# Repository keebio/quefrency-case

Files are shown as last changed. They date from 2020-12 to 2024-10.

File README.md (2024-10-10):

# Quefrency Keyboard Case

Case files for the [Quefrency](https://keeb.io/collections/quefrency-split-staggered-65-keyboard).

## Enclosed Case

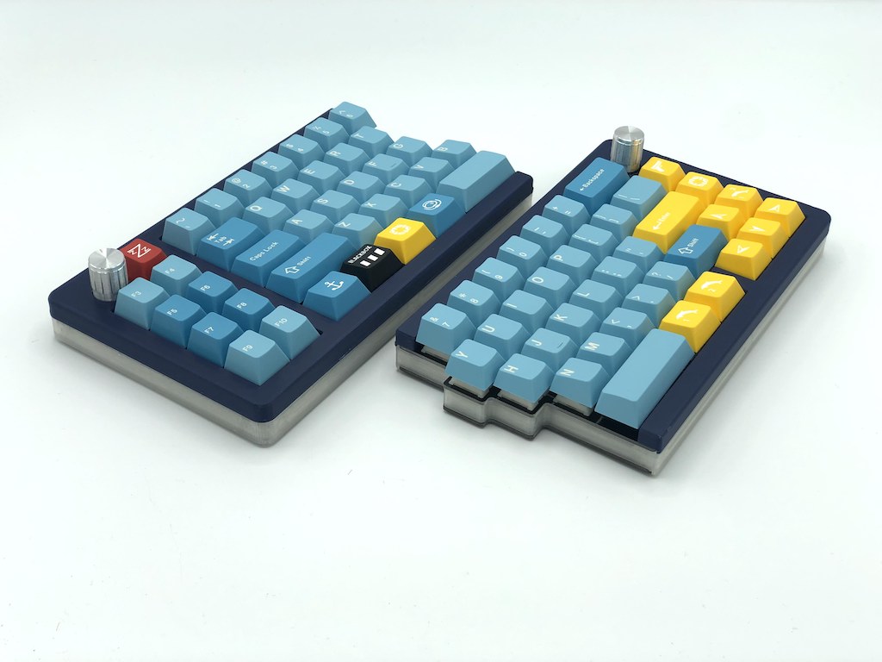
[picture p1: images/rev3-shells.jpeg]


Inside of the [enclosed-case directory](enclosed-case/) are files to print an enclosing shell around the board. They will need to be used in conjuction with the [FR4](https://keeb.io/products/quefrency-fr4-plates?utm_source=github) or [Aluminum plates](https://keeb.io/products/quefrency-black-aluminum-plates?utm_source=github) from the store.

These files are compatible with Rev. 2 through 6. For Rev. 2, use the middle layer files marked with `Rev. 2`.

## Rev. 3-6

The only difference between Rev. 2 and 3 is that Rev. 3 replaced the TRRS port with a USB-C port.

## License

These case files are released under the MIT License.

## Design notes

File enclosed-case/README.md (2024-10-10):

## Rev. 3-6 Case files



The top shell and mid layer files in this folder are to be used with FR4 plates. Each edge has been extended out by 2mm to cover up the sides of the FR4 plates.

The top shell has been designed to be threaded into directly from underneath using M2 screws that are 16mm in length.

For the right 65% half with blocker, the blocker is for the 2.75u/1.25u/1.25u/blocker/1u/1u/1u bottom row configuration.

These files are compatible with Rev. 3-6. If you have the prototype version of the Rev. 4 (Red PCB), the right half PCB is a bit wider, so you will need to use the `Rev. 4 Proto` version of the right half files. The regular version of the Rev. 4 has a purple PCB.

### Rev. 6

The left half PCB for the Rev. 6 slightly sticks out more on the right edge of the PCB, so it is not compatible with the mid layer STLs for Rev. 3-5. Use the Rev. 6 ones for Left Macro or Left No Macro, as the wall has been made thinner at that portion to allow the PCB to fit into the case properly.

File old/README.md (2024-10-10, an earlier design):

## Rev. 1 vs. Rev. 2

The difference between Rev 1 and Rev 2 plates are the following:

- Rev 2 does not have Alps support, while Rev 1 does
- Rev 2 adds ISO support and a few more bottom row layout options
- Rev 2 has a different arrangement of screw/standoff holes to allow for an acrylic mid layer to be used

## Rev. 2

All of the DXF files are in metric (millimeters).

### Switch Plates
The plate files in the [main rev2 directory](rev2/) are designed for 1.5mm thick plates. If doing acrylic plates, then either a thickness of 3mm or 5mm should be used. Files for these thicker plates can be found in the [3mm Plates](rev2/3mm Plates) and [5mm Plates](rev2/5mm Plates) directories. The difference with these thicker plates is that the stabilizer cutouts are larger to accomdate the stabilzer housing and wire.

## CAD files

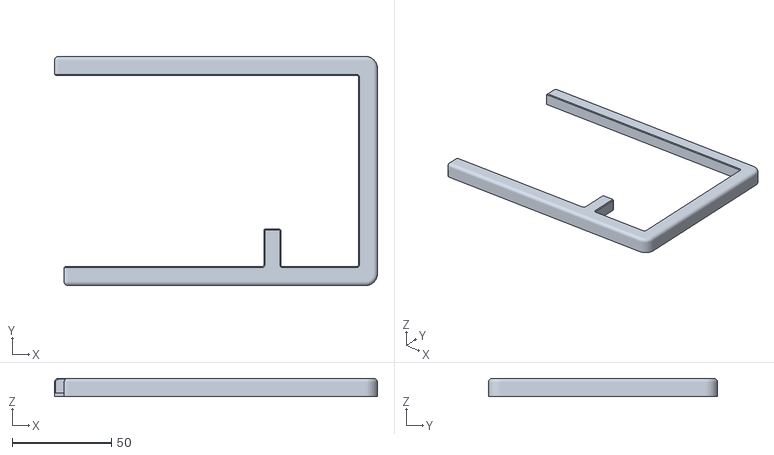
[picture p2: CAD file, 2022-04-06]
enclosed-case/Filleted Top Shells/Top Shell - Right 60 with Blocker.stl
162.4 x 115.2 x 9.30

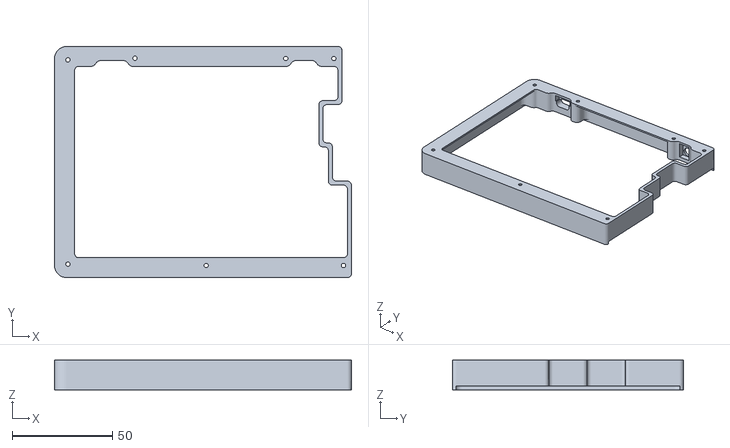
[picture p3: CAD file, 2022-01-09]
enclosed-case/Rev. 2/Mid Layer - Left No Macro for Rev. 2.stl
148.1 x 115.3 x 14.8

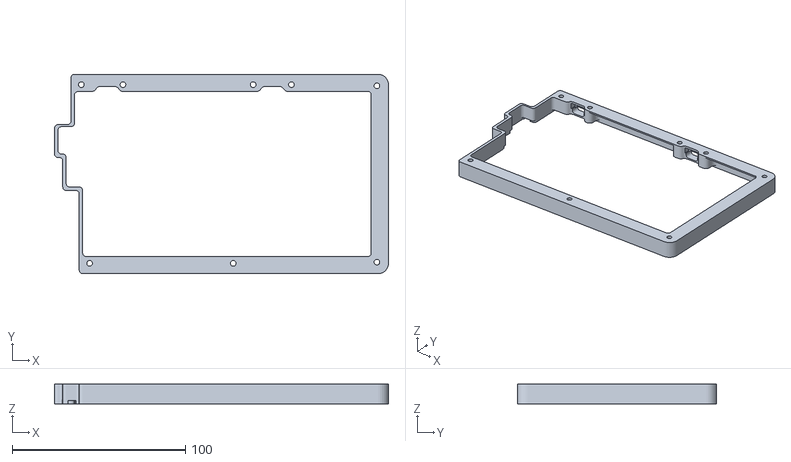
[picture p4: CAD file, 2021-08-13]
enclosed-case/Rev. 4 Proto/Mid Layer - Right 65 for Rev. 4 Proto.stl
193.0 x 115.2 x 11.3

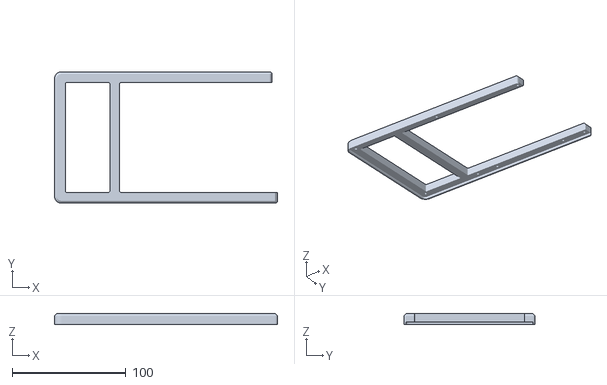
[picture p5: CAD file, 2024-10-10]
enclosed-case/Top Shell - Left Macro.stl
195.7 x 115.3 x 9.30

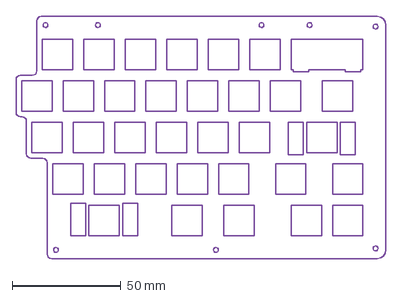
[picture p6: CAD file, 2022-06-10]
plates/switch-plate-blockered-right-60.dxf
169.9 x 111.2 mm

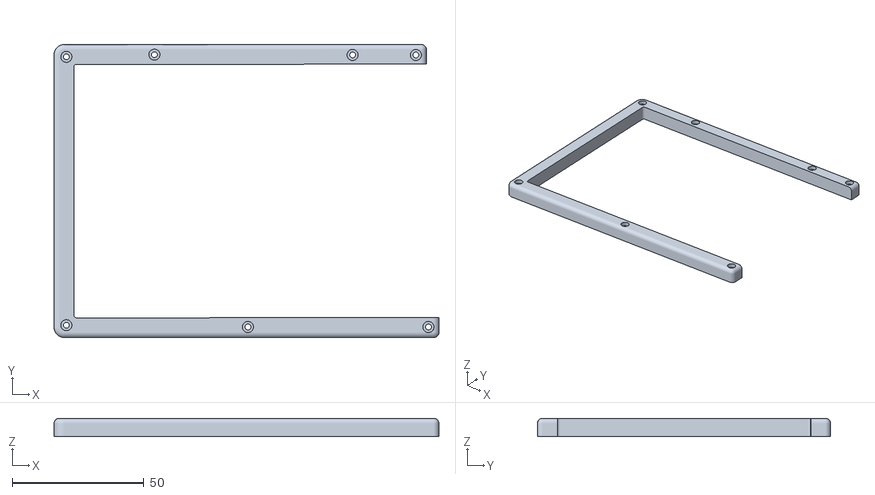
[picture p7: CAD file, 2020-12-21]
rev2/Top Shell - Left.stl
146.1 x 111.3 x 7.00

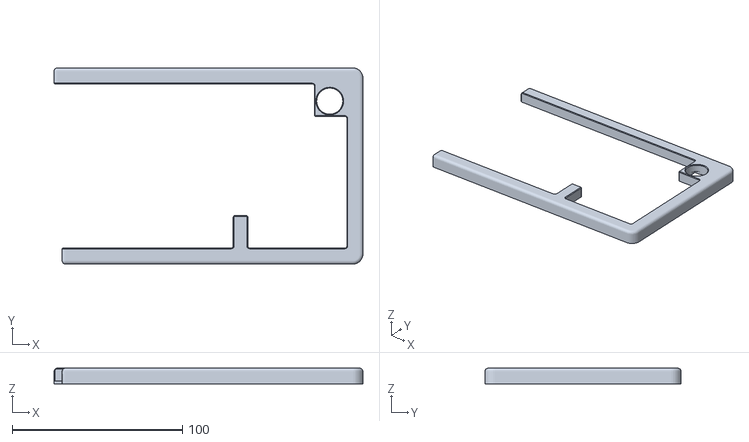
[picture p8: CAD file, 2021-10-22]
enclosed-case/Filleted Top Shells/Top Shell - Right 65 with Encoder and Blocker.stl
181.4 x 115.2 x 9.30

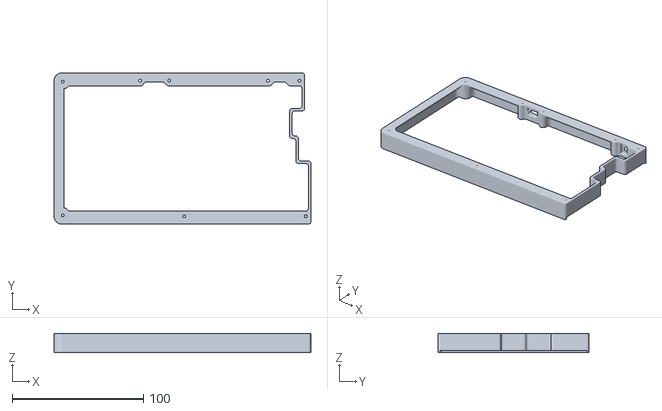
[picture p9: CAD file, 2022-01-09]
enclosed-case/Rev. 2/Mid Layer - Left Macro for Rev. 2.stl
195.7 x 115.3 x 14.8

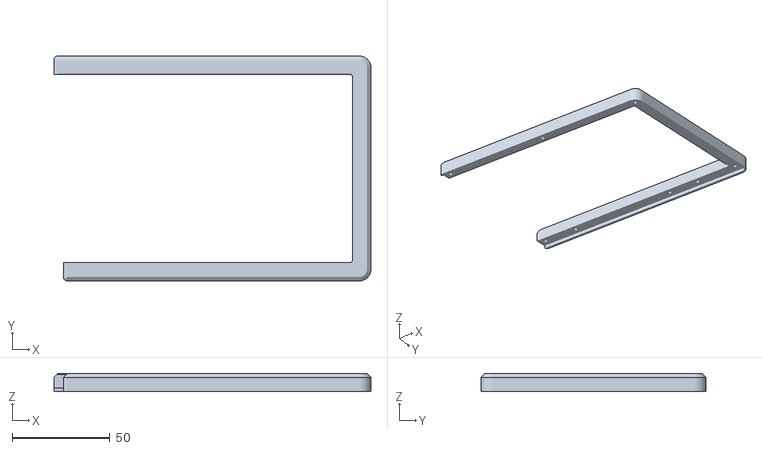
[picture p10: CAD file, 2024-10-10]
enclosed-case/Top Shell - Right 60.stl
162.4 x 115.2 x 9.30

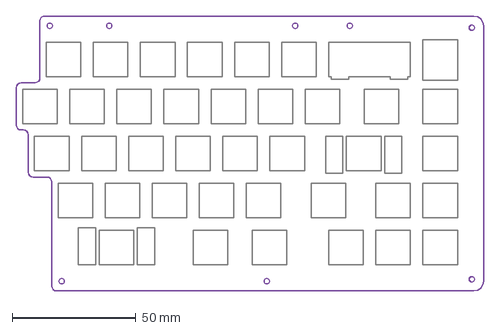
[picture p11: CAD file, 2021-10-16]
plates/switch-plate-blockered-right-65.dxf
189.0 x 111.2 mm

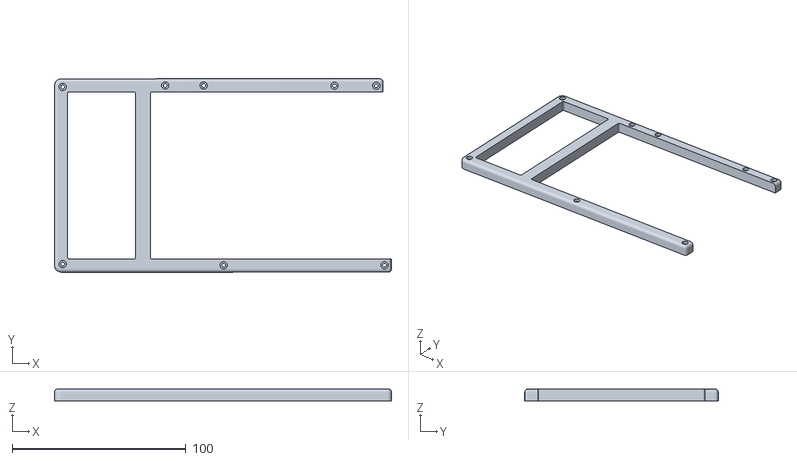
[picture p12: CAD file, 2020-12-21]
rev2/Top Shell - Left Macro.stl
193.7 x 111.3 x 7.00

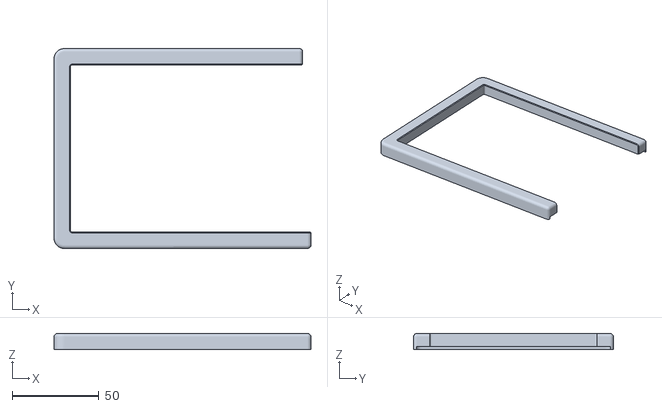
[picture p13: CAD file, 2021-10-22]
enclosed-case/Filleted Top Shells/Top Shell - Left 60.stl
148.1 x 115.3 x 9.30

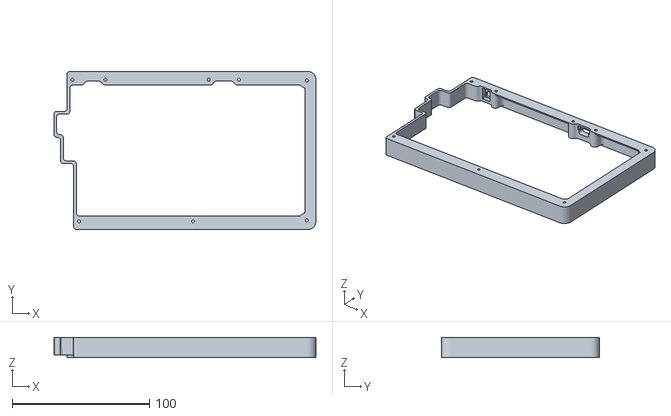
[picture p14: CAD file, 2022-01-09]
enclosed-case/Rev. 2/Mid Layer - Right 65 for Rev. 2.stl
191.0 x 115.2 x 14.8

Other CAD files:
rev2/3mm Plates/switch-plate-3mm-right-65.dxf
rev2/5mm Plates/switch-plate-5mm-right.dxf
rev2/3mm Plates/switch-plate-3mm-left.dxf
rev2/5mm Plates/switch-plate-5mm-left.dxf
enclosed-case/Top Shell - Left Macro and Encoder.stl
enclosed-case/Bottom Wedge - Left Macro.stl
enclosed-case/Bottom Wedge - Left No Macro.stl
enclosed-case/Bottom Wedge - Right 60.stl
enclosed-case/Bottom Wedge - Right 65.stl
enclosed-case/Filleted Top Shells/Quefrency Top Shells All - Fillet.f3d
enclosed-case/Filleted Top Shells/Top Shell - Left Macro with Encoder.stl
enclosed-case/Filleted Top Shells/Top Shell - Left Macro.stl
enclosed-case/Filleted Top Shells/Top Shell - Right 60.stl
enclosed-case/Filleted Top Shells/Top Shell - Right 65 for Rev. 4 Proto.stl
enclosed-case/Filleted Top Shells/Top Shell - Right 65 with Blocker.stl
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

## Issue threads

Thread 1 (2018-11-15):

Create 3D print top and bottom pieces

nooges, 2018-11-15:

szaghi, 2019-05-21:
My friend Luca has create the top and bottom plates design (for the 65% version), you can find them here

https://www.thingiverse.com/thing:3644626

danseely, 2019-05-28:
@nooges does this refer to entire case top & bottom parts? I'd love files for a hi-profile top lip, not sure if that would be included in what you were thinking here, or if you'd rather I make another issue just for that 😀

Closed 2021-11-01.

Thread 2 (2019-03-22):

too much tight tolerance for 3D print

szaghi, 2019-03-22:
Hi @nooges

thank you very much for sharing your work.

I have 3D printed your middle layers and they are great! However, the *tolerance" of the holes for usb and jack cables are too much "tight": they fit perfectly, but they must be installed before the pro micro are soldered and cannot be removed without desoldering. I have slightly modified your design allowing some more tolerance for that holes and now the middle layers can be installed and uninstalled effortless (I have attached some pictures of my current design).

Do you mind to publish your design and my modifications on thingiverse? There are much more 3D makers than on github.

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

donkalar, 2019-03-24:
If you do end up posting your mods on thingiverse, be sure to also post a link!

nooges, 2019-05-08:
Yeah go ahead.

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

szaghi, 2019-05-21:
I have published our efforts: I have cited you and this original source, let me know if it is fine or if I have to amend it.

https://www.thingiverse.com/thing:3644626

Virepri, 2019-05-23:
@szaghi do you plan to make a outer layer for the left hand macro version?

szaghi, 2019-05-23:
Hi @Virepri

I probably will do within other cases for the standard 65%. The problem is that I saw the left hand macro version (Reddit), but I am not able to find where to buy a PCB.

Do you have it? Where can I buy the left hand macro PCB?

Cheers

szaghi, 2019-05-24:
Forgive me, I have just see that the macro version is available on the keebio store, I will buy it and I'll try to build a case also for it, I do not know when... I have a lot of ongoing projects now.

Closed 2022-06-10.

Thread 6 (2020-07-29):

Rev 2 Mid Right 65 has intersecting faces

brandon099, 2020-07-29:
When trying to have these printed, looks like there are three intersecting faces on top of the USB-C port opening. Mid Left STL looks good.

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

nooges, 2020-08-10:
I'll have a more formal version of the mids soon with more form-fitting cutouts for the two jacks to replace the current STLs I posted up as a quick and dirty version.

Closed 2021-07-07.

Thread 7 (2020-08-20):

Provide STL files for 3D printing switch plate and bottom plate for rev2

jumar, 2020-08-20:
I'd like to print the switch plate and the bottom plate but my autocad skills are so bad that I did not find how to extrude the switch and bottom plate dxf file to generate a STL for printing.

Closed 2021-11-01.

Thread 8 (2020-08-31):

Provide an .SVG file with layers in addition to .AI

mscosti, 2020-08-31:
Hi there. Thanks for posting the raw .AI file that appears to have all the proper dimensions including the PCB hole locations.

Unfortunately, I do not have access to Adobe Illustrator, and am limited to Inkscape. While Inkscape can import .AI files, it seems it is not recognizing the layers in the .AI file, and instead I get one layer which is all of the other layers merged into 1, making it difficult and impractical to actually work with.

I tried following this solution in the inkscape forums which had me look at the objects present instead of the layers, but I'm just seeing a bunch of different individual paths. https://inkscape.org/forums/questions/preserve-layers-when-importing-ai-files/

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

If it's not too much trouble, I would greatly appreciate an SVG exported from Illustrator that still has individual named layers preserved, for those of us that don't have access to Illustrator.

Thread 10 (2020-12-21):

Quefrency Rev 2 middle layer incompatible with instructions

FThompson, 2020-12-21:
I'm building a Quefrency Rev 2, and I followed the instructions in the [build guide](https://docs.keeb.io/docs/quefrency-rev2-sinc-build-guide/#assemble-case). This guide says to attach the standoffs to the top plate and then slide the middle layer over the standoffs before attaching the bottom plate.

Issue: The thin section of the middle layer (where the ports fit) collide with the ports themselves when attempting this step. The thin section appears to fit between the ports and the top plate. However, they block the middle layer from sliding over the top. It appears that this middle layer would fit only if attached to the top plate before the PCB.

It seems that the build guide has the right idea to add the case as one of the later steps (nobody wants to try and solder around a middle layer). However, the models aren't compatible with these instructions.

The easiest fix would be to remove the thin sections around each port on the model.

nooges, 2020-12-21:
For the 3D printed layer, what you have to do is unscrews the standoffs from the switch plate, insert the standoffs into the middle layer, then fit the switch plate/PCB through the middle layer from the side.

Closed 2022-06-24.

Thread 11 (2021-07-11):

Rev 3 Top Shell have duplicated files

daniel2887, 2021-07-11:
These two files are the same - both include encoder:
* Top Shell - Right 65.stl
* Top Shell - Right 65 with Encoder.stl

Could you please share a corrected version of "Top Shell - Right 65.stl" without encoder?

nooges, 2021-07-11:
Fixed now with 7442bbba41e401c7da04f9b8a6b609b6b97d97a7

Closed 2021-07-11.

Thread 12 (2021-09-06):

quefrency rev3 right front-certer hole misplaced

midilicious, 2021-09-06:
the front center hole of the right 60 and 65% mid layer models are about 1cm right of the hole on the plates. the recesses in the top shell appear to be correctly placed

midilicious, 2021-09-12:
disregard. rev3 PCB shipped with rev2 plates. all the holes are in the right place and the USB C just fit in the TRRS cutout. shipping owes design a coffee
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

Closed 2021-09-12.

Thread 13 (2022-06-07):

Rev.4 missing 60% right layout

miromannino, 2022-06-07:
Hello, I am wondering where I can find the plate files for the 60% rev4 right side.
Isn't possible to have a 60% for the v4?
Thanks in advance for the reply

miromannino, 2022-06-07:
The only 60% one I can find for the switches plate is: [switch-plate-3mm-right.dxf ](https://github.com/keebio/quefrency-case/blob/master/rev2/3mm%20Plates/switch-plate-3mm-right.dxf)

But this has a long hole in the bottom part. According to this Keebio's video instead https://www.youtube.com/watch?v=ONEaWsojIn0&t=80s it seems there is a new plate that doesn't have that long gap at the bottom.

nooges, 2022-06-07:
You want this file: https://github.com/keebio/quefrency-case/blob/master/rev2/switch-plate-right.dxf

miromannino, 2022-06-08:
Uhm I saw that but like the video said, at the bottom there is a long opened part that would make show the pcb on rev4.

Attached the screenshots to show:

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

Instead a 60% for rev4 I guess should be something like this? (red parts are the ones taken from the rev4 drawing)

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

I just did in Illustrator, I have no idea how to change these files.

miromannino, 2022-06-10:
This is the problem I am talking about. I have a rev4 pcb, but the plates are from the 60% version 2, and the pcb is visible:

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

Thank you in advance

nooges, 2022-06-10:
Ah okay, I'll get a new file posted up for it.

nooges, 2022-06-10:
Okay, I've added it in now: https://github.com/keebio/quefrency-case/blob/master/rev4/switch-plate-rev4-right-60.dxf

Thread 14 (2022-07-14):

Gap too narrow in mid layer's USB-C ports

joseprio, 2022-07-14:
I wanted to print the mid layers using a 3D printing service, but they pointed out that there's a particular area where the gap is just 0.25mm, and they recommend a minimum gap of 0.8mm as otherwise there's a risk it would break. The issue seems to be that the USB-C port gets too near the bottom "lip".
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

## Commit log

2018-08-21 Add mid layer files for 3D printing
    [Quefrency Left Middle Layer.stl, Quefrency Right Middle Layer.stl]
2018-09-17 Add 3D print mid layer for 65% right half
    [Quefrency 65 Right Middle Layer.stl]
2018-09-17 Add plate file for 65%
2019-03-06 Add plate design for left macro half
2019-03-06 Add mid layer for left macro half
    [Quefrency Left Macro Middle Layer.stl]
2019-03-08 Widen cutout for Pro Micro
    [Quefrency Left Macro Middle Layer.stl]
2020-05-07 Move files to rev1 directory
    [Quefrency 65 Right Middle Layer.stl, Quefrency Left Macro Middle Layer.stl, Quefrency Left Middle Layer.stl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]
2020-05-09 Add generated DXF files for plates and layers
    [bottom-plate-left-macro.dxf, bottom-plate-left.dxf, bottom-plate-right-65.dxf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]
2020-05-11 Fix corner rounding on left macro mid layer
    [mid-layer-left-macro.dxf]
2020-07-08 Add Rev. 2 STEP exports of PCB
2020-07-24 Fix left macro mid layer dxf
    [mid-layer-left-macro.dxf]
2020-07-24 Add STL files for 3D printing mids
    [Mid - Left 60.stl, Mid - Left Macro.stl, Mid - Right 60.stl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]
2020-08-07 Add 3mm and 5mm plate files
    [bottom-plate-left-macro.dxf, bottom-plate-right-65.dxf, switch-plate-3mm-left-macro.dxf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]
2020-08-11 Change top shell DXFs to metric (mm)
    [top-shell-left-macro.dxf, top-shell-left.dxf, top-shell-right-65.dxf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]
2020-08-11 Convert switch plate and bottom plate DXFs to metric
    [bottom-plate-left-macro.dxf, bottom-plate-left.dxf, bottom-plate-right-65.dxf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]
2020-08-11 Convert mid layer DXFs to metric
    [mid-layer-left-macro.dxf, mid-layer-left.dxf, mid-layer-right-65.dxf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]
2020-08-11 Fix path for mid layer
    [mid-layer-left-macro.dxf]
2020-08-25 Add reset hole to bottom plates
    [bottom-plate-left-macro.dxf, bottom-plate-left.dxf, bottom-plate-right-65.dxf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]
2020-11-08 Update stab cutouts for 5mm plates
    [switch-plate-5mm-left-macro.dxf, switch-plate-5mm-left.dxf, switch-plate-5mm-right-65.dxf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]
2020-12-20 Fix top shell files to have more clearance between shell edge and keycaps
    [top-shell-left-macro.dxf, top-shell-left.dxf, top-shell-right-65.dxf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]
2020-12-21 Add 3D print top shell files
    [Top Shell - Left Macro.stl, Top Shell - Left.stl, Top Shell - Right 60.stl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]
2021-07-01 Add Rev. 3 files
    [Mid Layer - Left 60.stl, Mid Layer - Left Macro.stl, Mid Layer - Right 65.stl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]
2021-07-01 Add another top shell for rev 3
    [Top Shell - Right 65 with Encoder and Blocker.stl]
2021-07-01 Add right 65 shells w/o encoder cover
    [Top Shell - Right 65 Blocker.stl, Top Shell - Right 65.stl]
2021-07-02 Add corrected Right 65 blocker shell
    [Top Shell - Right 65 Blocker.stl]
2021-07-06 Add Top Shell for left macro w/o encoder
    [Top Shell - Left Macro.stl]
2021-07-07 Add right 60 shell files
    [Mid Layer - Right 60.stl, Top Shell - Right 60.stl]
2021-07-11 Fix duplicated file
    [Top Shell - Right 65.stl]
2021-08-12 Fix bottom plate height cutout and fillets to allow bottom plate to fit better
    [Mid Layer - Left Macro.stl, Mid Layer - Right 65.stl]
2021-08-13 Add fixed right 60 mid
    [Mid Layer - Right 60.stl]
2021-08-13 Add files for Rev. 4 proto PCB
    [Mid Layer - Right 65 for Rev. 4 Proto.stl, Top Shell - Right 65 for Rev. 4 Proto.stl, Top Shell - Right 65 with Encoder for Rev. 4 Proto.stl]
2021-08-13 Update mid layer for left 60
    [Mid Layer - Left 60.stl]
2021-08-31 Fix incorrect bottom middle hole location for left mid w/o macro
    [Mid Layer - Left 60.stl]
2021-09-18 Add files for tented mids
    [Mid Layer - Left 60 Tenting.stl, Mid Layer - Left Macro Tenting.stl, Mid Layer - Right 65 Tenting.stl]
2021-10-16 Move case files for rev 3 and 4, update README
    [Mid Layer - Left 60 Tenting.stl, Mid Layer - Left 60.stl, Mid Layer - Left Macro Tenting.stl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]
2021-10-16 Add F360 design file for top shells
    [Quefrency Top Shells All.f3d]
2021-10-16 Update top shells to have larger screw hole size and changed inner top edge from fillets to chamfers
    [Quefrency Top Shells All.f3d, Top Shell - Left 60.stl, Top Shell - Left Macro with Encoder.stl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]
2021-10-19 Fix encoder housing width
    [Quefrency Top Shells All.f3d, Top Shell - Left Macro with Encoder.stl, Top Shell - Right 65 with Encoder and Blocker.stl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]
2021-10-21 Add STEP files for Rev. 4 PCBs
2021-10-22 Reduce plate height slot from 2mm to 1.8mm
    [Quefrency Top Shells All.f3d, Top Shell - Left 60.stl, Top Shell - Left Macro with Encoder.stl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]
2022-01-09 Add Rev. 2 compatible mid layer for enclosed case
    [Mid Layer - Left 60 for Rev. 2.stl, Mid Layer - Left Macro for Rev. 2.stl, Mid Layer - Right 60 for Rev. 2.stl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]
2022-02-07 Add bottom wedge pieces
    [Bottom Wedge - Left 60.stl, Bottom Wedge - Left Macro.stl, Bottom Wedge - Right 60.stl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]
2022-04-06 Fix location of bottom middle hole for right 60% mid
    [Mid Layer - Right 60.stl]
2022-04-06 Add Right 60% top with blocker
    [Top Shell - Right 60 with Blocker.stl]
2022-06-10 Add switch plate for Rev. 4 60% right half
    [switch-plate-rev4-right-60.dxf]
2022-06-24 Rename enclosed case directory
    [Bottom Wedge - Left 60.stl, Bottom Wedge - Left Macro.stl, Bottom Wedge - Right 60.stl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]
2024-10-10 Reorganize mid layers and top shells
    [Bottom Wedge - Left No Macro.stl, Mid Layer - Left Macro for Rev. 2.stl, Mid Layer - Left No Macro for Rev. 2.stl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]
2024-10-10 Move plate files
    [switch-plate-blockered-right-60.dxf, switch-plate-blockered-right-65.dxf, switch-plate-left-macro.dxf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]
2024-10-10 Remove older PCB .step files and compress remaining ones
2024-10-10 Move older case files
    [Mid - Left 60.stl, Mid - Left Macro.stl, Mid - Right 60.stl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]
